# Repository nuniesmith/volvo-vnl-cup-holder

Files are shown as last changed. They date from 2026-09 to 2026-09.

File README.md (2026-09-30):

# Volvo VNL cup holder clone

A 3D-printed clone of the stock **Volvo VNL dash cup holder (Volvo 84752175 REV P02)** for the ribbed dash shelf, where holders clip onto **any notch** and four fit side by side. The cup is **enlarged to fit the owner's YETI Rambler 36 oz bottle** (listed 3.75 in / 95.3 mm across), which does not fit the stock holder. It is printed on an **Ender 3 Neo (220 × 220 × 250 mm)**.

The clone is printed in **two parts, like the original**:

- **Main body:** the cup, mounting flange and clip posts (grey on the stock part)
- **Clip:** the spring-loaded arm on the underside (orange on the stock part), returned by a compression spring from the ordered 304 stainless kit (**0.5 × 6 × 25 mm**, roughly 2–4× softer than stock)

The stock part also has a **torsion spring on a metal pin** inside the box, which loads the grey tongue ([photo](pictures/box_inside_torsion_spring.jpg)). The clone needs that one too, or a printed flex tongue instead.

**Current print checkpoint: [v0.2 mount test pieces](src/stl/v0.2/README.md)** (snap posts for the ledge holes), alongside the [v0.1 bottle rings and step gauge](src/stl/v0.1/README.md). No cup holder body or clip is modeled yet.

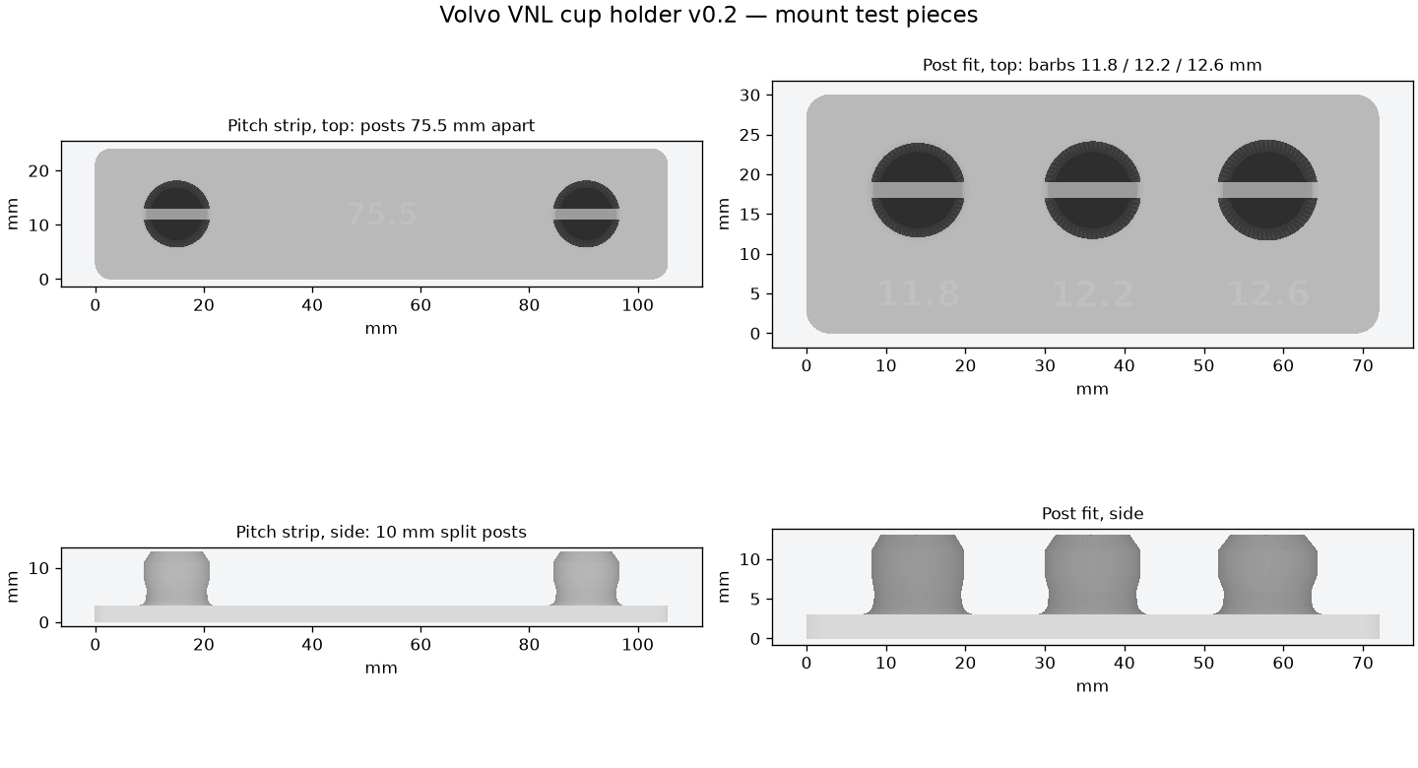
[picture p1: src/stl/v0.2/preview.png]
v0.2 mount tests


## Start here

- [v0.2 mount tests: snap posts for the ledge holes](src/stl/v0.2/README.md)
- [v0.1 gauges: what to print and how to read them](src/stl/v0.1/README.md)
- [Photo review of the stock part](docs/photo-review.md)
- [Caliper measurements needed for the clone](docs/measurements.md)
- [Current tasks](docs/todo.md)

## What we know so far

These are approximate tape readings from the photos, not caliper values.

| Feature | Photo reading | Source |
|---|---:|---|
| Stock cup opening, inside at the rim | ~4.0 in (~101 mm) | [IMG_0159](pictures/IMG_0159.JPEG) |
| Stock cup, across the bottom | **96 mm** (caliper, likely outside) | owner |
| Stock cup floor, inside | ~3.3–3.4 in (~85 mm), scaled from the photo | [underside_floor](pictures/underside_floor.jpg) |
| Box outside width | **93.2–93.3 mm** (caliper) | [photo](pictures/box_width_93_3mm.jpg) |
| Width across the top at the posts | **105.0 mm** (caliper) | [photo](pictures/top_flange_105mm.jpg) |
| Box length along the side | **102.2 mm** (caliper) | [photo](pictures/box_length_102_2mm.jpg) |
| Clip-post edge to where the cup curve starts | ~2.2 in (~56 mm) | [clip_post_flange](pictures/clip_post_flange.jpg) |
| Overall length, mount flange to far rim | ~6.6 in (~168 mm) | [IMG_0158](pictures/IMG_0158.JPEG) |
| Overall width across the underside | ~5.1 in (~130 mm) | [IMG_0160](pictures/IMG_0160.JPEG) |
| Orange clip length | ~5.1 in (~129 mm) | [IMG_0156](pictures/IMG_0156.JPEG) |
| Orange clip width at the socket end | **23.9 mm** (caliper) | [photo](pictures/clip_socket_width_23_9mm.jpg) |
| Orange clip end tab | **17.6 mm** (caliper) | [photo](pictures/clip_end_17_6mm.jpg) |
| Stock spring free length | ~1.05 in (~27 mm) | [IMG_0157](pictures/IMG_0157.JPEG) |
| Ledge hole diameter | **11.5 mm** (caliper) | owner |
| Hole spacing (neighbouring holes) = post spacing | **75.5 mm** (caliper) | owner |
| Ledge thickness at the holes | **20 mm** (caliper) | owner |
| Shelf rib pitch (lower lip) | ~1.55 in (~39.5 mm) from photo | [shelf_rib_pitch](pictures/shelf_rib_pitch.jpg) |
| Two holders, center to center | at least 2 holes = **151 mm** (from the hole spacing) | [two_holders_spacing](pictures/two_holders_spacing.jpg) |
| YETI Rambler 36 oz diameter | **3.75 in (95.3 mm)**, listed spec; base read ~3.6 in | [IMG_0161](pictures/IMG_0161.JPEG) |

The stock rim (~101 mm) is wider than the bottle (95.3 mm), but the cup tapers to about 85 mm at the floor,
so the bottle jams partway down. The grey spring tongue also pushes into the cup. The clone needs a bore of
about 97–98 mm most of the way down; the bottle rings pick the exact size.

**How it mounts:** two split posts on the top flange snap up into a row of round holes under the upper
dash ledge ([photo](pictures/ledge_underside_holes.jpg)), and the bottom sits at the ribbed lip. At about
151 mm or more between holder centers (each holder uses two neighbouring holes), the enlarged ~103 mm cups have plenty of room.
See [photo review: mounting](docs/photo-review.md#mounting-from-the-in-truck-photos).

## What has been checked

Only CAD checks. The v0.1 and v0.2 STLs are closed, single-body meshes within the printer's build
volume ([mesh_checks.json](src/stl/v0.1/mesh_checks.json)). Nothing has been printed or fitted.

## Revision history

| Directory | Role |
|---|---|
| [v0.1](src/stl/v0.1) | Bottle-fit rings (96.0 / 97.5 / 99.0 mm) and a stock-cup step gauge |
| [v0.2](src/stl/v0.2) | Mount test pieces: split snap posts (11.8 / 12.2 / 12.6 mm barbs) and a 75.5 mm pitch strip |

## Layout

```
pictures/   reference photos of the stock part and bottle
docs/       photo review, measurement sheet, tasks
src/stl/    one folder per CAD revision (OpenSCAD source, STLs, scripts, preview)
```

Repository: [nuniesmith/volvo-vnl-cup-holder](https://github.com/nuniesmith/volvo-vnl-cup-holder).

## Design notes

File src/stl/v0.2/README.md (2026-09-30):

# v0.2 — mount test pieces

**Small test prints for the snap posts only. No cup holder body or clip yet.**

They check that the clone's posts fit the holes under the dash ledge before the full body is modeled.

Mount test pieces

## Owner measurements used (2026-09-29/30)

| Feature | Value | In the CAD |
|---|---:|---|
| Ledge hole diameter | 11.5 mm | Shank 11.1 mm (0.4 mm clearance); barb 11.8–12.6 mm |
| Post spacing, center to center | 75.5 mm | Pitch strip posts 75.5 mm apart |
| Ledge thickness | 20 mm | Posts don't pass through; they grip inside the hole |
| Post height | 10 mm | Posts 10 mm above the plate; barb 2–5 mm below the tip; 8 mm slot |

The 17.6 and 23.9 mm readings are the **orange clip**: 17.6 mm across its end tab
([photo](../../../pictures/clip_end_17_6mm.jpg)) and 23.9 mm across the square-socket end
([photo](../../../pictures/clip_socket_width_23_9mm.jpg)). They aren't used here.

The post's own diameter isn't needed: the shank is sized from the 11.5 mm hole, and `post_fit.stl` tries
three barb sizes so the fit is picked by test rather than measured.

## Print and test

Print at **100% scale**, plate flat on the bed with the posts up, no supports. PETG or PLA is fine for a test.

1. **post_fit.stl**: three single posts with barbs of **11.8, 12.2 and 12.6 mm** (engraved beside each).
   Push each post into one ledge hole. Pick the smallest barb that snaps in firmly, stays put when you tug,
   and can still be pulled out without breaking. If all are loose, the barb needs to be bigger; if all are too
   tight to push in, smaller. Change `fit_barbs` and re-export.
2. **pitch_strip.stl**: two posts **75.5 mm** apart with the 12.2 mm barb. Push both into two holes at once.
   They should drop in square, with no forcing sideways. If they bind, the spacing is off; note which way.

Each post is split by a 2.2 mm slot so the two halves squeeze together going in. The barb has a lead-in taper
at the tip and a back-taper below it.

## Reproduce

```sh
python export_models.py    # needs OpenSCAD
python validate_meshes.py  # needs NumPy; writes mesh_checks.json
python make_preview.py     # needs Matplotlib; writes preview.png
```

`mesh_checks.json` records closed oriented edges, triangle validity, one connected body and bed/Z bounds.
It does not certify fit or snap strength.

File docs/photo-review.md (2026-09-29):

# Photo review of the stock cup holder

Photos taken 2026-09-29 on an iPhone 17 Pro Max. The tape readings are approximate:
parallax and tape angle make them good to about ±0.1 in.

## Part markings (IMG_0155)

Molded on the underside of the body:

- **84752175 REV P02** (Volvo part number and revision)
- **8230-001VN**, **MA/2104P FR**, **10058762**, **63409/35787** (supplier and mold codes)
- **>PC/ABS<**, meaning the body is a polycarbonate/ABS blend. PETG or ASA are reasonable printed substitutes for cab heat; plain PLA may soften in a hot truck.

## What each photo shows

| Photo | View | Notes |
|---|---|---|
| [IMG_0149](../pictures/IMG_0149.JPEG) | From the mount end, looking into the cup | Top mounting flange with **two split clip posts**. The grey spring tongue comes down through a slot in the flange into the cup. Tulip-shaped cup walls with open side cutouts. |
| [IMG_0150](../pictures/IMG_0150.JPEG) | Three-quarter side | Box-shaped mount section behind the round cup; V-shaped side cutout; tongue curling into the cup |
| [IMG_0151](../pictures/IMG_0151.JPEG) | Mount end, head-on | Open box section behind the cup, with the orange clip visible below it |
| [IMG_0152](../pictures/IMG_0152.JPEG) | Other side | Same V cutout; stiffening step molded into the box side |
| [IMG_0153](../pictures/IMG_0153.JPEG) | Underside, assembled | Orange clip across the round floor, pivoting on two side pins; square socket at the mount end |
| [IMG_0154](../pictures/IMG_0154.JPEG) | Underside, top-down | The same, with part numbers visible |
| [IMG_0155](../pictures/IMG_0155.JPEG) | Underside, clip removed | Two pivot lugs (one with a hole), a **spring boss** near the centre, a small post at the mount end, and two flat pads where the clip sits. The spring sat in the boss. |
| [IMG_0156](../pictures/IMG_0156.JPEG) | Orange clip and spring on a tape | Clip ~5.1 in long; pivot pins about halfway along; spring pocket with a small hole; open square socket at one end |
| [IMG_0157](../pictures/IMG_0157.JPEG) | Spring on a tape | Free length ~1.05 in (~27 mm), OD roughly 9 mm. Some rust. |
| [IMG_0158](../pictures/IMG_0158.JPEG) | Top, tape along the length | ~6.6 in from the flange edge to the far rim |
| [IMG_0159](../pictures/IMG_0159.JPEG) | Top, tape across the cup | Inside diameter at the rim ~4.0 in |
| [IMG_0160](../pictures/IMG_0160.JPEG) | Underside, tape across | ~5.1 in across the widest point |
| [IMG_0161](../pictures/IMG_0161.JPEG) | YETI Rambler 36 oz base | ~3.6 in at the base; listed body diameter 3.75 in (95.3 mm) |
| [mount_end_width](../pictures/mount_end_width.jpg) | Looking into the cup from above the mount end, tape across the box | Box/mount end ~3.9 in (~99 mm) wide. Two split clip posts on the top edge. |
| [clip_post_flange](../pictures/clip_post_flange.jpg) | Top face of the mount flange | Two split posts at the outer corners; ~2.2 in (~56 mm) from the post edge to where the cup curve starts. The grey tongue comes through the flange here. |
| [box_inside_torsion_spring](../pictures/box_inside_torsion_spring.jpg) | Inside the open box | **Torsion spring on a metal pin** near the top, loading the grey tongue. The box is ~4.1 in (~104 mm) long. The orange clip sticks out of the far end. |
| [underside_floor](../pictures/underside_floor.jpg) | Underside, clip installed | Scaled from the tape, the dark floor disc is ~3.3–3.4 in (~85 mm) and the outside of the cup ~3.85 in (~98 mm). The tape doesn't start at an edge, so caliper this. |
| [truck_mounting_shelf](../pictures/truck_mounting_shelf.jpg) | In the truck | The stock holder sits in a pocket at the left end of a recessed shelf under the upper dash ledge. The shelf has a lip with about nine small vertical ribs. The owner confirmed that holders clip onto **any notch** along this lip and can be moved around; four fit side by side. |

| [ledge_underside_holes](../pictures/ledge_underside_holes.jpg) | Underside of the upper dash ledge, looking up | A **row of round holes** along the ledge. The holder's two split clip posts snap up into these. Scaled against the hole size, the holes look evenly spaced at about the rib pitch. |
| [stock_holder_installed](../pictures/stock_holder_installed.jpg) | Stock holder in the truck | Top flange tight under the ledge (posts in the holes); box against the back wall; bottom resting at the ribbed lip. |
| [shelf_rib_pitch](../pictures/shelf_rib_pitch.jpg) | Tape along the ribbed lower lip | Ribs at ~0.05, 1.56, 3.11 and 4.67 in on the tape: **pitch ~1.55 in (~39.5 mm)**. |
| [two_holders_spacing](../pictures/two_holders_spacing.jpg) | Two stock holders side by side, from above | The flanges nearly touch. Reading the flange edges against the tape gives a center spacing of **~4.6 in (~118 mm), i.e. 3 notches**; reading the tongues gives ~4.1 in. Needs a direct measurement. |
| [spring_kit](../pictures/spring_kit.jpg) | Ordered spring kit | 240-piece **304 stainless compression** kit: wire × OD × length of 0.3×4, 0.4×5 and 0.5×6 mm, each in 10/15/20/25/30 mm. |

## Mounting (from the in-truck photos)

- **Top:** two split clip posts on the flange snap up into the **round holes** under the upper ledge.
- **Pitch:** the ribs on the lower lip are ~39.5 mm apart; the holes appear to share that pitch.
  With the flange ~99 mm wide, posts near its corners would be **2 pitches (~79 mm) apart**. To confirm.
- **Spacing:** two stock holders appear to sit **3 notches (~118 mm) apart**. The enlarged cup
  (~103 mm outside) fits within that, so four Yeti holders should still fit side by side. To confirm.
- **Bottom:** most likely the square end of the orange clip catches the ribbed lip between two ribs,
  which is what stops the holder sliding; pressing the clip releases it. To confirm.

## Springs

| Spring | Wire × OD × free length (mm) | Notes |
|---|---|---|
| Stock clip spring | ~0.8–1.0 × ~9 × ~27 (photo, unmeasured) | Some rust |
| Kit, strongest 25 mm | 0.5 × 6 × 25 | Also 0.5 × 6 × 30 for more preload |

Spring rate scales with wire⁴ / coil diameter³, so the kit's 0.5 × 6 mm springs are **roughly 2–4× weaker**
than the stock one, possibly more. The clip should still return, but more softly. The v0.2 clip will size
its spring pocket for the **6 mm OD** springs (≈6.6 mm bore) and compress them to about 18–20 mm installed
for preload. If the return is too weak, use the 30 mm spring or two springs side by side.
The kit has no **torsion** spring for the grey tongue.

## Clone notes

- The clip and spring are a separate sub-assembly, so a two-part print (body + clip) matches the original.
- There are **two springs**: the compression spring under the orange clip (~27 mm, photo reading) and a
  **torsion spring** on a metal pin that loads the grey tongue. The tongue could instead be a printed flex
  finger (PETG flexes well), but a flex finger may take a set in cab heat.
- The ordered **25 mm** springs (a kit) are about 2 mm shorter than the stock compression spring.
  Model the clip's spring pocket and the body boss around the **new** spring's OD, wire size and
  free length, and check that the preload still returns the clip.
- The clip's pivot pins are molded in. On a printed clip, they can be printed in place (clip lying
  flat, pins horizontal) or replaced with a metal pin through a hole. Decide after measuring the pin diameter.
- The tulip cup walls, clip posts and flange need supports or a split print. The body's print orientation
  gets decided once the mount interface is measured.

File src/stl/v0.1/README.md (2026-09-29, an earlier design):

# v0.1 — measurement gauges

**These are measuring aids, not cup holder parts.** They answer two questions before the body is modeled:
how big the new cup must be for the YETI Rambler 36 oz (listed 3.75 in / 95.3 mm), and what shape the stock cup is inside.

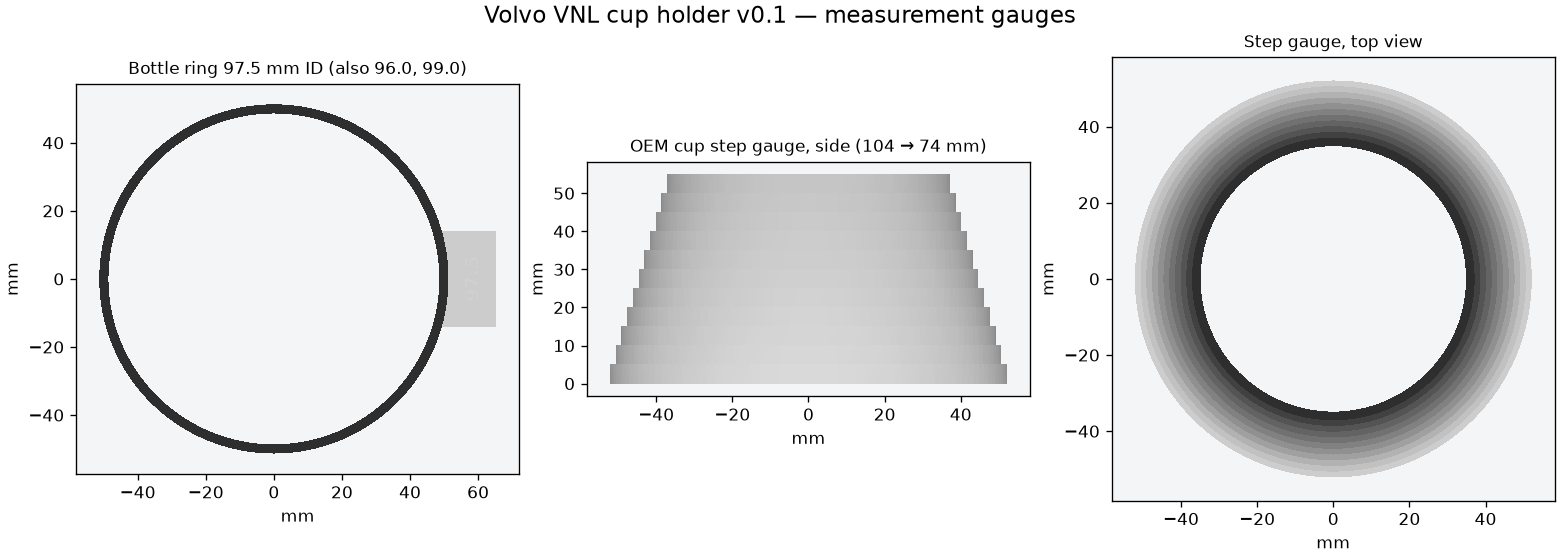
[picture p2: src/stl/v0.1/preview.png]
Gauges


## Print and test

Print at **100% scale**, flat as supplied, with no supports. PLA is fine.

1. **bottle_ring_96.0.stl, bottle_ring_97.5.stl, bottle_ring_99.0.stl** — 20 mm tall rings
   with their inside diameter engraved on the tab. Slide each one over the **bottom** of the Yeti,
   then up the body as far as the cup will reach (about 60–70 mm).
   Record the smallest ring that slides on and off easily without catching.
   That diameter, plus a little clearance, sets the new cup bore.
   96.0 should be snug on a 95.3 mm bottle and 99.0 loose. Aim for easy in and out with a little play,
   since the truck vibrates. If none fits, change `ring_id` and re-export.
2. **cup_step_gauge.stl** — a hollow stepped cone, **104 mm down to 74 mm in 3 mm steps**,
   each 5 mm tall. The notch marks step 0, the widest. Push the **narrow end** into the stock cup
   with the grey spring tongue held back. Record which step stops at the rim, and how far down
   the narrow end reaches. Repeat with the tongue released. This shows how tapered the stock cup is,
   so the clone can copy its shape while enlarging it.

| Step | Diameter (mm) | Height from wide base (mm) |
|---:|---:|---:|
| 0 | 104 | 0–5 |
| 1 | 101 | 5–10 |
| 2 | 98 | 10–15 |
| 3 | 95 | 15–20 |
| 4 | 92 | 20–25 |
| 5 | 89 | 25–30 |
| 6 | 86 | 30–35 |
| 7 | 83 | 35–40 |
| 8 | 80 | 40–45 |
| 9 | 77 | 45–50 |
| 10 | 74 | 50–55 |

## Reproduce

```sh
python export_models.py    # needs OpenSCAD
python validate_meshes.py  # needs NumPy; writes mesh_checks.json
python make_preview.py     # needs Matplotlib; writes preview.png
```

`mesh_checks.json` records closed oriented edges, triangle validity, one connected body and
bed/Z bounds. It does not certify fit.

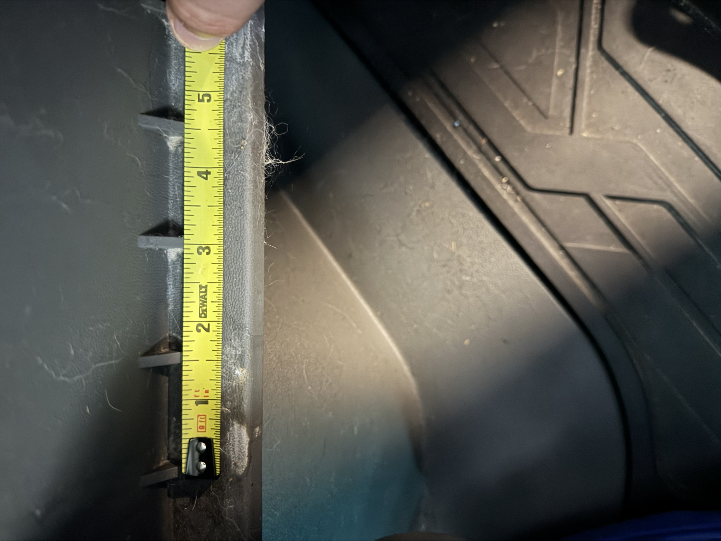
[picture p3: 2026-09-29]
pictures/shelf_rib_pitch.jpg

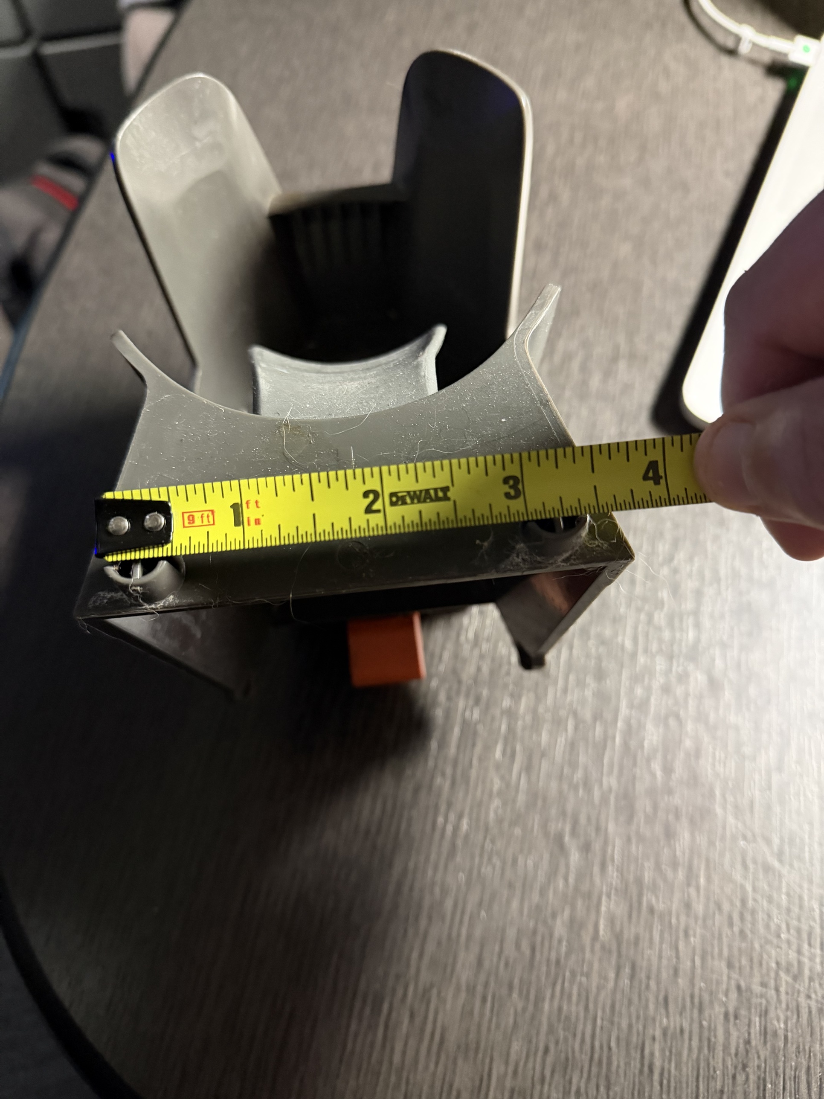
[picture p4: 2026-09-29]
pictures/mount_end_width.jpg

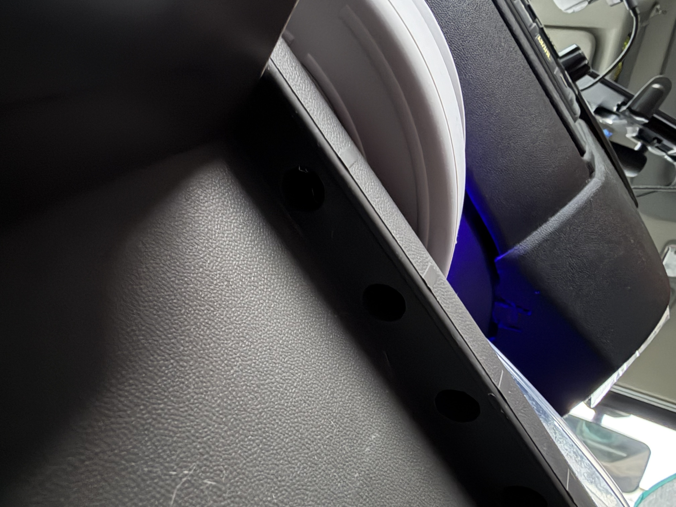
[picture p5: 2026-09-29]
pictures/ledge_underside_holes.jpg

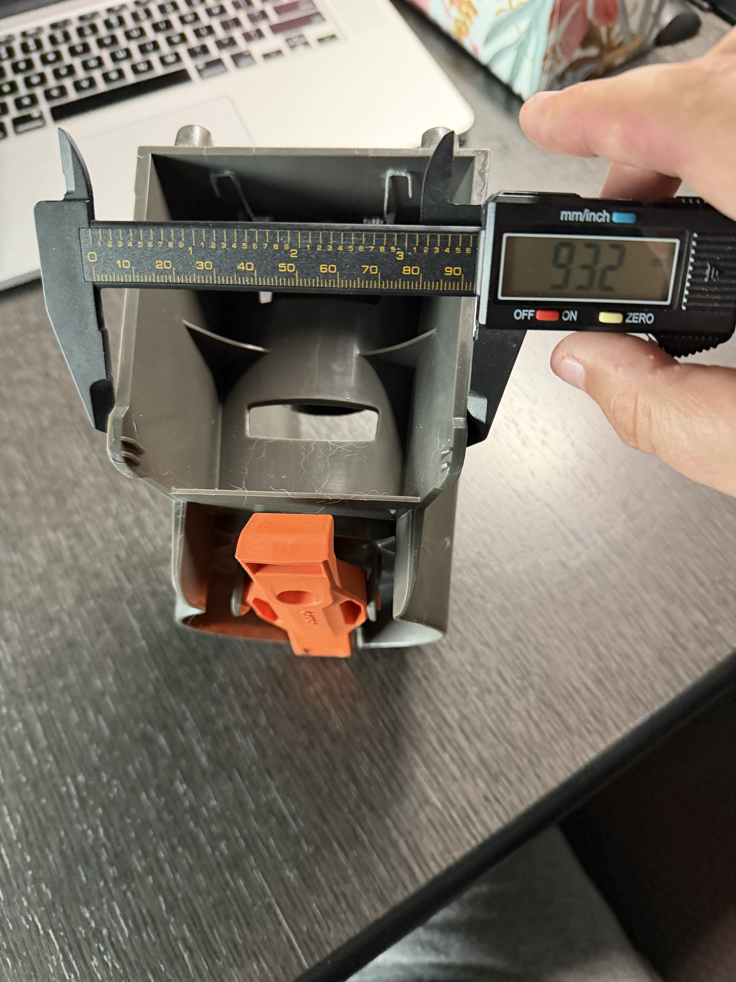
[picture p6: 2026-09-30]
pictures/box_width_top_93_2mm.jpg

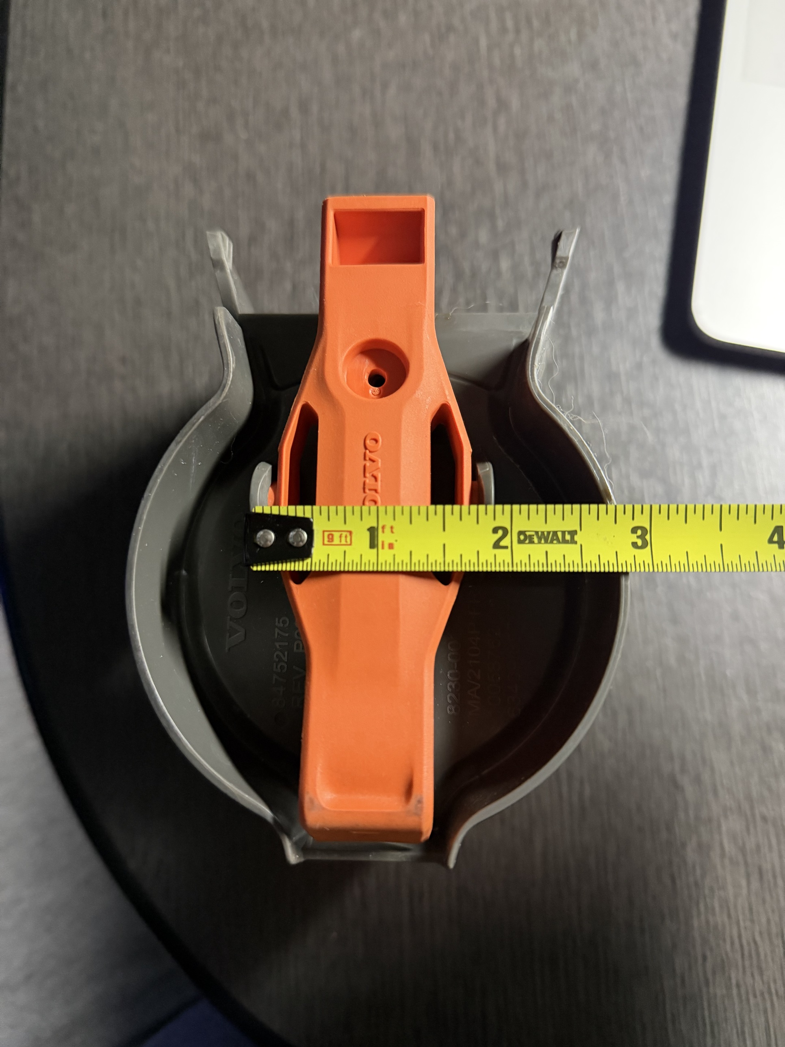
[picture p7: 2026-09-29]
pictures/underside_floor.jpg

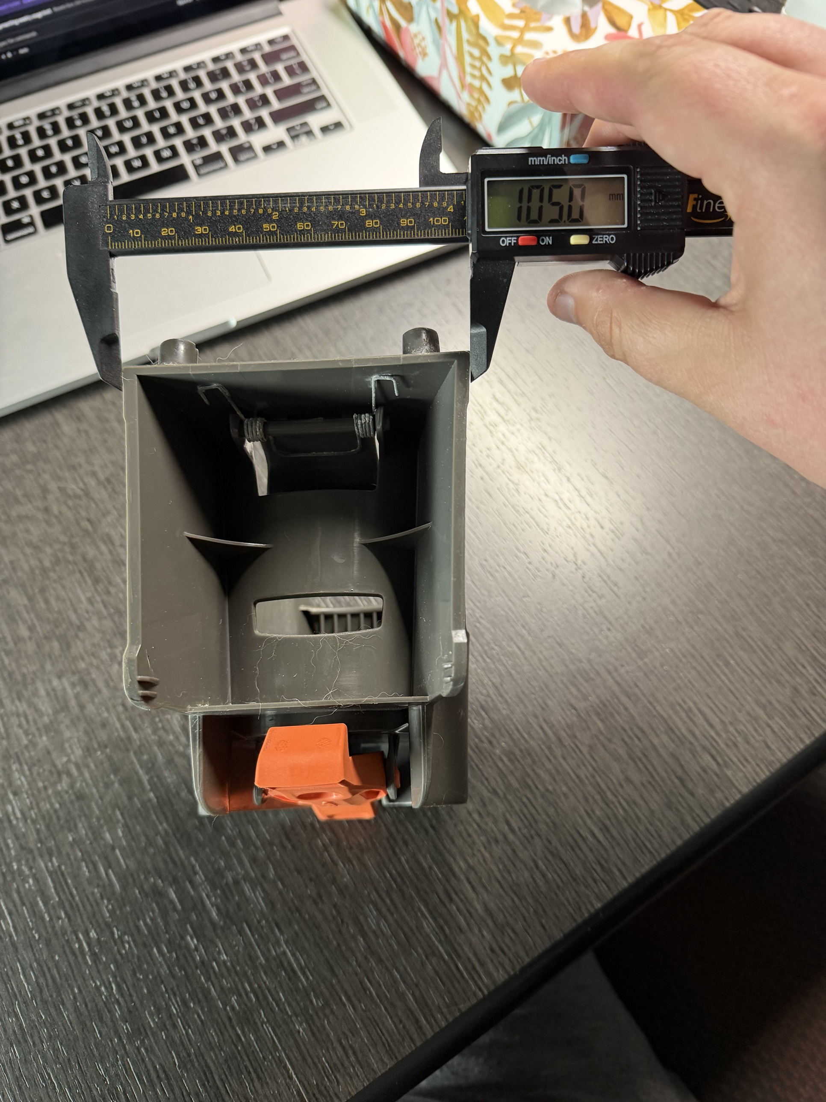
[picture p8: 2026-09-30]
pictures/top_flange_105mm.jpg

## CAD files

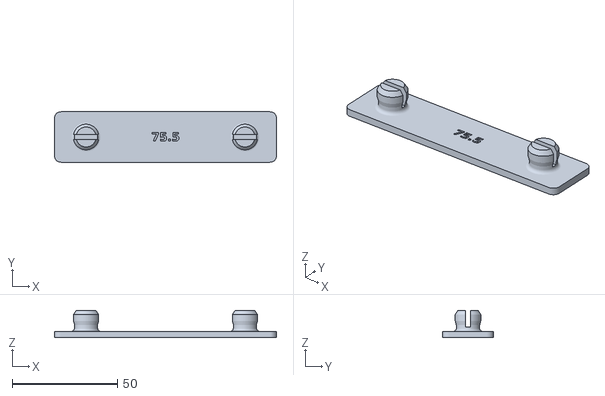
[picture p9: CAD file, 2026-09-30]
src/stl/v0.2/pitch_strip.stl
105.5 x 24.0 x 13.0

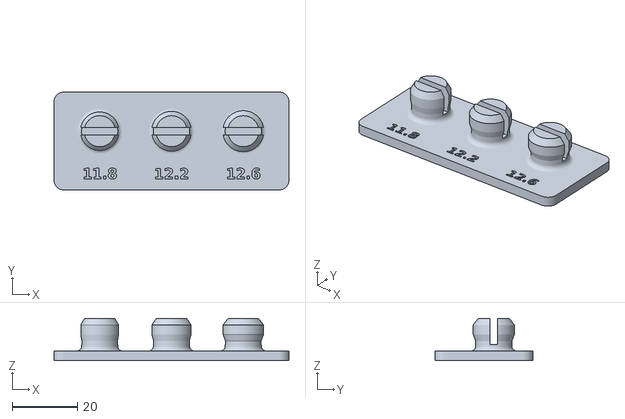
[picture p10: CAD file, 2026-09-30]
src/stl/v0.2/post_fit.stl
72.0 x 30.0 x 13.0

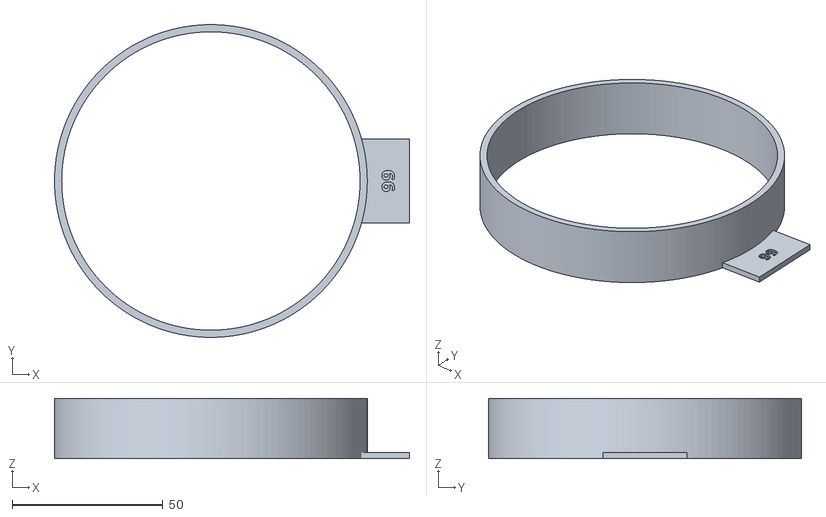
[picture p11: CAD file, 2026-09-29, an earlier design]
src/stl/v0.1/bottle_ring_99.0.stl
117.8 x 103.8 x 20.0

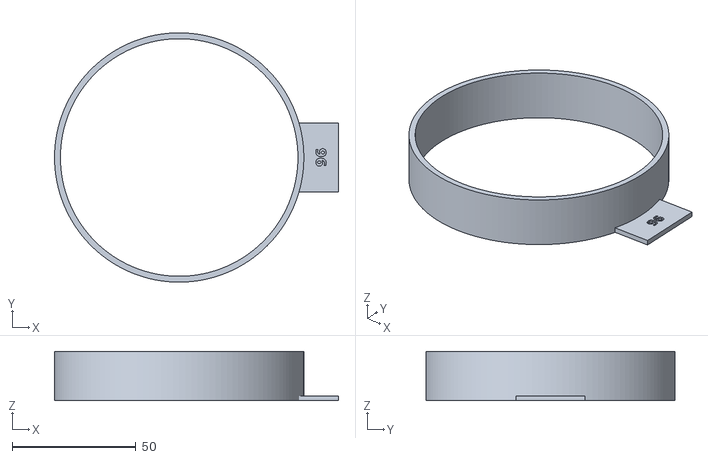
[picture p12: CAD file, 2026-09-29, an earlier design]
src/stl/v0.1/bottle_ring_96.0.stl
114.8 x 100.8 x 20.0

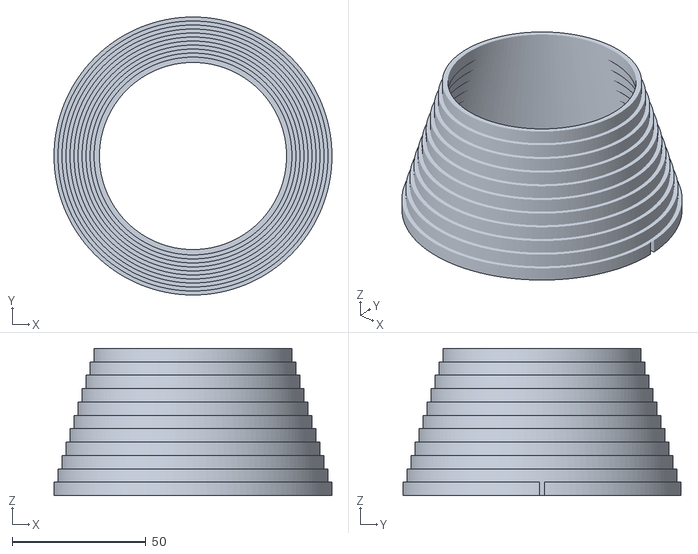
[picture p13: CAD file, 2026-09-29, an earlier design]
src/stl/v0.1/cup_step_gauge.stl
104.0 x 104.0 x 55.0

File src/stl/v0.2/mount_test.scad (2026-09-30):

// v0.2 MOUNT TEST ONLY: split snap posts for the holes under the dash ledge.
// Owner caliper values (2026-09-29): ledge hole 11.5 mm, post/hole spacing
// 75.5 mm center to center, ledge 20 mm thick; stock post 10 mm tall (2026-09-30).
// Dimensions in mm. Print at 100%, plate flat on the bed, posts up, no supports.
part="pitch_strip"; // pitch_strip | post_fit
$fn=64;
hole_d=11.5;       // measured
post_pitch=75.5;   // measured, center to center
post_h=10;         // measured: stock post height above the flange
shank_clear=0.4;   // shank is this much smaller than the hole
lead_d=9.5;        // tip diameter, for an easy start into the hole
barb_h=3;          // straight band of the barb
barb_from_top=2;   // top of the barb band below the tip
taper_h=2;         // barb back-taper down to the shank
slot_w=2.2;        // cross slot that lets the two halves squeeze together
slot_depth=8;      // slot length from the tip down
plate_t=3;
fit_barbs=[11.8,12.2,12.6]; // post_fit coupon: interference trial sizes
strip_barb=12.2;             // pitch_strip uses the middle size until one is chosen
shank_d=hole_d-shank_clear;
assert(slot_depth<post_h-1,"Slot would cut through the post base");
assert(max(fit_barbs)<hole_d+2,"Barb too large to push in");

module label(s,size=4){
 text(s,size=size,font="DejaVu Sans:style=Bold",halign="center",valign="center");
}
// Revolved post profile: shank, back-taper, barb band, lead-in cone to the tip.
module post(barb_d){
 zb=post_h-barb_from_top;          // top of barb band
 difference(){
  rotate_extrude() polygon([
   [0,-0.01],[shank_d/2,-0.01],
   [shank_d/2,zb-barb_h-taper_h],
   [barb_d/2,zb-barb_h],
   [barb_d/2,zb],
   [lead_d/2,post_h],
   [0,post_h]]);
  translate([-barb_d,-slot_w/2,post_h-slot_depth]) cube([2*barb_d,slot_w,slot_depth+1]);
 }
 // Base fillet ring so the post doesn't snap off at the plate.
 rotate_extrude() difference(){
  translate([shank_d/2-0.01,0]) square(1.5);
  translate([shank_d/2+1.5,1.5]) circle(r=1.5);
 }
}
module plate(w,d){
 hull() for(x=[3,w-3],y=[3,d-3]) translate([x,y]) cylinder(r=3,h=plate_t);
}
// Two posts at the measured spacing: checks pitch, seating and pull-out together.
module pitch_strip(){
 w=post_pitch+30; d=24;
 difference(){
  plate(w,d);
  translate([w/2,d/2,plate_t-0.6]) linear_extrude(1) label(str(post_pitch),4);
 }
 for(x=[15,15+post_pitch]) translate([x,d/2,plate_t-0.01]) post(strip_barb);
}
// Three single posts with different barb sizes: pick the one that snaps and holds.
module post_fit(){
 n=len(fit_barbs); gap=22; w=gap*n+6; d=30;
 difference(){
  plate(w,d);
  for(i=[0:n-1]) translate([gap/2+3+i*gap,5,plate_t-0.6]) linear_extrude(1) label(str(fit_barbs[i]),3.2);
 }
 for(i=[0:n-1]) translate([gap/2+3+i*gap,d/2+3,plate_t-0.01]) post(fit_barbs[i]);
}
if(part=="pitch_strip") pitch_strip();
else if(part=="post_fit") post_fit();
else assert(false,str("Unknown part: ",part));

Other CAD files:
src/stl/v0.1/bottle_ring_97.5.stl
src/stl/v0.1/measure_gauges.scad

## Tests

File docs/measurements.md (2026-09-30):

# Measurements needed for the clone

Use calipers where possible and record values in mm.
For the snap posts, see the [measuring guide](measure_posts.png) (A, B, C, D). Fill in the "Measured" column
(or reply with the numbers) and the CAD will be built from them. Photos with a caliper
in view help settle any ambiguity.

## Yeti bottle

| # | Feature | Photo estimate | Measured |
|---:|---|---:|---|
| Y1 | Bottle model and size | YETI Rambler 36 oz (#47234550) | ✔ owner |
| Y2 | Body diameter (listed spec 3.75 in = 95.3) | ~91 at the base (photo) | |
| Y3 | Diameter 30 mm and 60 mm up from the base | — | |
| Y4 | Smallest bottle ring that slides freely (v0.1 test) | — | |

## Truck mounting spots

| # | Feature | Measured |
|---:|---|---|
| T1 | Where do the new holders go? | **Any notch on the ribbed shelf lip; holders can be moved. Four fit side by side.** (owner) |
| T2 | Rib pitch (center to center) | ~39.5 mm from photo; ribs are on the lower lip and don't set the hole spacing |
| T3 | Rib thickness and height; lip thickness and height | |
| T4 | How the bottom of the holder grips the lip (orange clip's square end between two ribs?), and how you release it | |
| T5 | Center-to-center spacing of two stock holders side by side | ~118 mm (3 notches) from the flange edges, photo; confirm |
| T6 | **Ledge holes:** diameter, spacing, ledge thickness | **11.5 mm hole; 75.5 mm between neighbouring holes; ledge 20 mm thick** (owner) |
| T7 | Do the holes line up with the ribs, or sit halfway between them? | |

## Main body (stock part)

| # | Feature | Photo estimate | Measured |
|---:|---|---:|---|
| B1 | Mounting flange width × depth × thickness | ~99 wide; ~56 post edge to cup curve | **105.0 across the top at the posts** (owner, [photo](../pictures/top_flange_105mm.jpg)); depth and thickness still needed |
| B2 | Clip post diameter, barb (widest) diameter, height, slot width, and center-to-center spacing | spacing likely ~79 mm (2 pitches) | **spacing 75.5 mm; height 10 mm** (owner); barb size picked by the v0.2 `post_fit` test |
| B3 | Box section outside width × height × length | ~99 wide, ~104 long | **93.2–93.3 wide, 102.2 long** (owner, [photo](../pictures/box_width_93_3mm.jpg), [photo](../pictures/box_width_top_93_2mm.jpg), [photo](../pictures/box_length_102_2mm.jpg)) |
| B4 | Cup inside diameter at the rim | ~101 | |
| B5 | Cup inside diameter at the floor, and cup depth | ~85 floor (scaled) | **96 across the bottom of the cup** (owner; likely outside); inside floor and depth still open |
| B6 | Step gauge result: step at the rim, and how deep the narrow end reached (v0.1 test) | — | |
| B7 | Wall thickness of the cup and box | — | |
| B8 | Pivot lug spacing, lug thickness and hole diameter | — | **47.5 outside to outside across the two pivot lugs** (owner, [photo](../pictures/pivot_lugs_47_5mm.jpg)); lug thickness and hole still needed |
| B9 | Spring boss outside/inside diameter and height | — | |
| B10 | Overall length, flange to far rim | ~168 | |
| B11 | Torsion spring: pin diameter and length, coil OD, leg lengths, and where the legs bear | — | |

## Clip (orange part)

| # | Feature | Photo estimate | Measured |
|---:|---|---:|---|
| C1 | Overall length × width × thickness | ~129 long | **23.9 wide at the square-socket end; 17.6 across the end tab** (owner, [photo](../pictures/clip_socket_width_23_9mm.jpg), [photo](../pictures/clip_end_17_6mm.jpg)) |
| C2 | Pivot pin diameter and length; distance from each end | pins ~halfway | |
| C3 | Spring pocket diameter and depth; distance from the pivot | — | |
| C4 | Square socket inside size and depth | — | |
| C5 | Angle of travel: how far it swings from rest to fully pressed | — | |
| C6 | What the clip does in the truck (latch, release, fold-out?) | — | |

## Springs

| # | Feature | Stock | New (ordered) |
|---:|---|---:|---|
| S1 | Free length | ~27 | 25 or 30 (kit) |
| S2 | Outside diameter | ~9 | 6 (kit's largest) |
| S3 | Wire diameter | ~0.8–1.0 (photo) | 0.5 |
| S4 | Compressed length when installed | — | |

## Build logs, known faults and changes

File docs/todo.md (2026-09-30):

# Tasks

Updated 2026-09-29. [v0.1 gauges](../src/stl/v0.1/README.md) · [Measurements](measurements.md) · [Photo review](photo-review.md)

## Decided

- [x] Goal: clone the stock VNL cup holder (84752175) for the ribbed dash shelf (four fit side by side).
- [x] Enlarge the cup so the **YETI Rambler 36 oz** (3.75 in / 95.3 mm) fits; the stock holder is too small.
- [x] Print in **two parts**, the main body and the clip, like the original.
- [x] Use the 304 stainless compression spring kit (0.5 × 6 × 25 mm, or × 30 mm for more preload).

## Done

- [x] Review all 13 photos; record markings, material (PC/ABS) and approximate tape readings.
- [x] Export v0.1 bottle rings and the stock-cup step gauge.
- [x] Resize the bottle rings to 96.0 / 97.5 / 99.0 mm for the 95.3 mm Rambler 36 oz.
- [x] Record the mount width, box length, floor size and torsion spring from the second photo set.

## Next

- [ ] Print the bottle rings; record the smallest ring that slides freely along the lower bottle (Y4).
- [ ] Print the step gauge; record the stock cup taper (B6).
- [ ] Take the caliper measurements in [measurements.md](measurements.md), especially the mount (B1–B3), pivots (B8, C2) and springs (S2–S4).
- [x] Mounting: holders clip onto any notch of the ribbed shelf lip and can be moved; four fit side by side (owner).
- [x] Read the rib pitch from the photo: ~39.5 mm (1.55 in).
- [x] Mount identified: two split posts snap into round holes under the upper ledge.
- [x] Spring kit: 304 stainless, largest 0.5 × 6 mm in 25/30 mm; roughly 2–4× weaker than stock.
- [x] Caliper the ledge holes and clip posts: 11.5 mm hole, 75.5 mm post spacing, 20 mm ledge, 17.5 / 24 mm on the post (owner).
- [x] 17.6 / 23.9 mm identified as orange clip dimensions (end tab, socket-end width), not post dimensions.
- [x] Box 93.2–93.3 mm wide and 102.2 mm long; 105.0 mm across the top at the posts; 47.5 mm across the pivot lugs (owner).
- [x] Stock post height 10 mm (owner); v0.2 re-exported with 10 mm posts. Barb size comes from the `post_fit` test.
- [x] 96 mm is across the bottom of the stock cup (owner).
- [ ] Owner also gave 17 mm ("barb on the hook"): confirm which part this was.
- [x] Neighbouring ledge holes are 75.5 mm apart (owner), the same as the post spacing. Holders sit at least 2 holes (151 mm) apart center to center.
- [x] Side-by-side clearance: at 151 mm minimum center spacing, the ~103 mm Yeti cup clears its neighbours.
- [ ] Confirm how the bottom of the holder grips the lip (T4).
- [ ] Decide on the grey tongue: reuse a torsion spring, or a printed flex finger (B11).
- [ ] Pick a filament: PETG or ASA suggested for cab heat.

## v0.2 (after measurements)

- [x] Export v0.2 mount tests: `post_fit.stl` (barbs 11.8 / 12.2 / 12.6 mm) and `pitch_strip.stl` (75.5 mm).
- [ ] Print the v0.2 mount tests; pick the barb size and confirm the pitch in the truck.
- [ ] Model the clip with a pocket for the 6 mm OD kit spring (~6.6 mm bore, ~18–20 mm installed); test pivot and return.
- [ ] Model the full body with the enlarged, tapered cup; decide the print orientation and supports.
- [ ] Assemble the body, clip and spring; test the Yeti fit, clip action and rattles in the truck.
- [ ] Print the second set once the first one fits.

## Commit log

2026-09-29 Set up repo structure and v0.1 CAD from the reference photos
    Add README, docs and a parametric OpenSCAD v0.1 folder with export,
    mesh-validation and preview scripts, following the truck-gps layout.
    Claude-Session: https://claude.ai/code/session_01GspfW6RzL6x6FFXjPYGow1
    [bottle_ring_92.0.stl, bottle_ring_93.5.stl, bottle_ring_95.0.stl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]
2026-09-29 Resize bottle rings for YETI Rambler 36 oz; add second photo set
    The Rambler 36 oz is listed at 3.75 in (95.3 mm), so the 92-95 mm rings
    were all too small; export 96.0/97.5/99.0 mm instead. Record the mount
    width, box length, floor size, torsion spring and truck shelf photos.
    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
    [bottle_ring_92.0.stl, bottle_ring_93.5.stl, bottle_ring_95.0.stl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]
2026-09-29 Record the owner's answer on mounting: any notch on the shelf lip
    Holders clip onto any rib notch and can be moved; four fit side by side.
    Add the notch-pitch, rib and lip measurements the mount needs, and flag
    side-by-side clearance for the enlarged cup.
    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
2026-09-29 Record mount, notch pitch, holder spacing and spring kit from photos
    Two split posts snap into a row of holes under the upper ledge; ribs on
    the lower lip are ~39.5 mm apart; two stock holders appear to sit 3
    notches (~118 mm) apart, so the ~103 mm Yeti cup still fits four across.
    The ordered kit's strongest spring is 0.5 x 6 mm, roughly 2-4x softer
    than stock. Add the caliper checks the mount coupon needs.
    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
2026-09-30 Add v0.2 mount test pieces from the owner's caliper values
    Split snap posts for the 11.5 mm ledge holes: a three-barb fit test
    (11.8/12.2/12.6 mm) and a two-post strip at the measured 75.5 mm
    spacing. Record the hole, spacing and ledge values; 17.5 mm is taken
    as the post height until the 17.5/24 mm readings are confirmed.
    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
    [mount_test.scad, pitch_strip.stl, post_fit.stl]
2026-09-30 Record orange clip calipers; flag v0.2 post height as unmeasured
    The 17.6 and 23.9 mm readings are the orange clip (end tab and
    socket-end width), not the snap posts. Mark post_h as a placeholder and
    hold the v0.2 print until the stock post height is measured.
    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
    [mount_test.scad]
2026-09-30 Record 75.5 mm hole spacing; update measuring guide
    Neighbouring ledge holes are 75.5 mm apart (same as the post spacing),
    so holders sit at least 151 mm apart and the Yeti cup has room. Mark D
    as measured and label the posts as part of the grey holder body.
    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
2026-09-30 Record 47.5 mm across the clip pivot lugs
    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
2026-09-30 Set v0.2 snap posts to the measured 10 mm height and re-export
    The owner measured the stock post at 10 mm. Shorten the barb, taper and
    slot to suit, re-export post_fit and pitch_strip (mesh checks pass),
    and lift the hold-off-printing note.
    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
    [mount_test.scad, pitch_strip.stl, post_fit.stl]
2026-09-30 Record 96 mm across the bottom of the stock cup
    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
